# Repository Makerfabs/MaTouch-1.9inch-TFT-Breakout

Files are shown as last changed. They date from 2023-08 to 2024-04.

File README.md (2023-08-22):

MaTouch 1.9“ TFT Breakout

```c++
/*
Version:		V1.1
Author:		Charlin
Create Date:	2023/8/14
Note:

*/
```

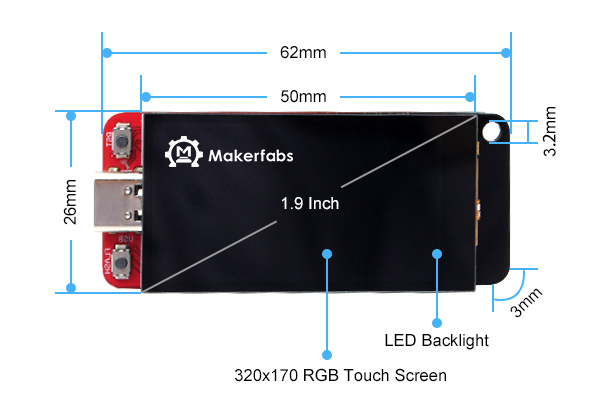
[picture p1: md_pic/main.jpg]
main


# Makerfabs

[Makerfabs home page](https://www.makerfabs.com/)

[Makerfabs Wiki](https://wiki.makerfabs.com/)

## Intruduce

Product Link:[MaTouch 1.9“ TFT Breakout](https://www.makerfabs.com/MaTouch-1.9-inch-TFT-Breakout.html)

Wiki Link : []()

Makerfabs MaTouch 1.9” has got lots of interests, but we got many feedback that there the ESP32S3 pins should be breakout, for users’ application, so we designed this new board.

Compares to the old version, there main updates are the GPIO all been breakout, users can prototype it more easily with a breadboard, or use it as a “controller” for other boards by inserting it to other boards.

## Features

Specs:
- Controller: ESP32-S3
- Wireless: WiFi& Bluetooth 5.0
- LCD: 1.9", 320x170 resolution, driver ST7789V2
- LCD interface: 8 bit 8080
- Touch Panel Driver: CST816D
- USB: USB Native, Type-C
- Power Supply: USB Type-C 5.0V(4.0V~5.25V); 3.7V Lipo battery
- Button: Flash button and reset button
- MicroSD: Yes
- Arduino support: Yes
- MicroPython support: Yes
- Operation temperature: -40℃ to +85℃

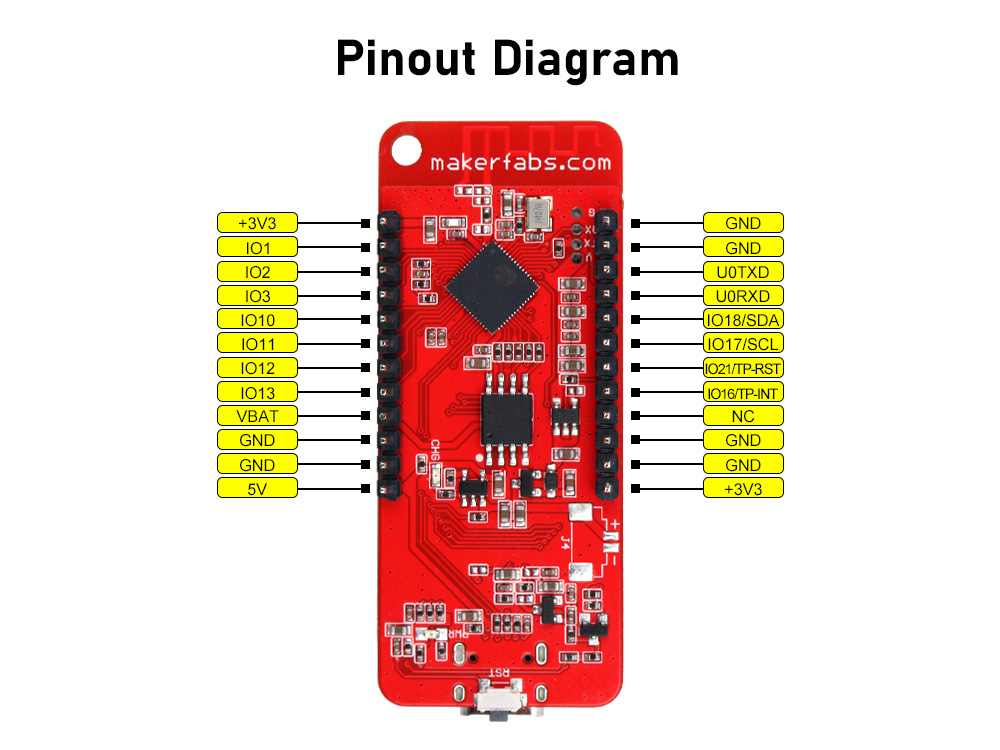
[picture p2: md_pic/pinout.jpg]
pinout


# Usage

## Libraries

Related library versions

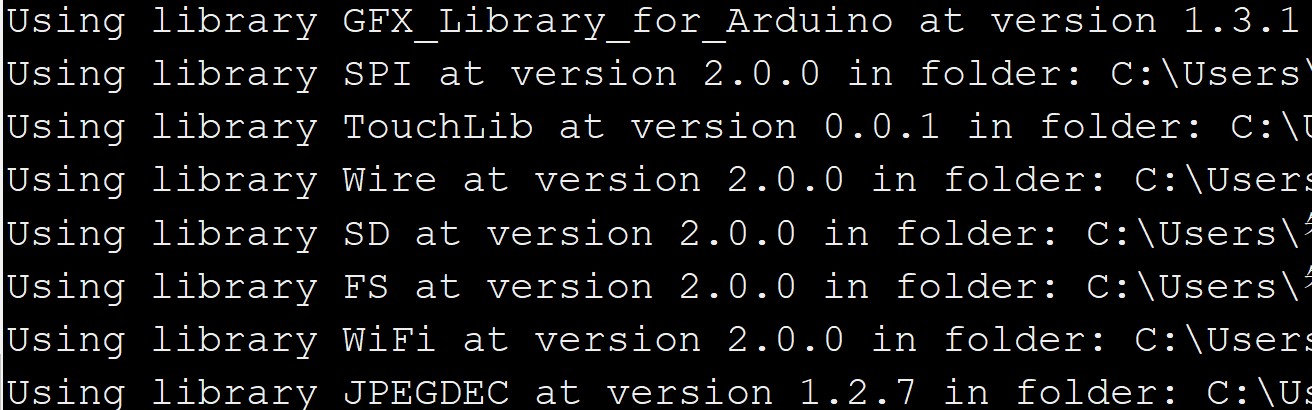
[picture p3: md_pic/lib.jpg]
library


- Use type-c use cable connect USB-TTL to PC.
- Select "ESP32-S3 DEV Module"
- Select PSRAM "OPI PSRAM"

"mf_Lvgl" library is modified from Lvgl library (version 8.3.2). 

Please unzip "lib/mf_Lvgl.zip"."TouchLib" and copy to arduino library directory.

## Example

### firmware

Factory test program

### squareline_demo

SquareLine demo, connected DHT11 sensor, button, LED.

[Youtube](https://www.youtube.com/watch?v=VayIuLey8po&t=3s)

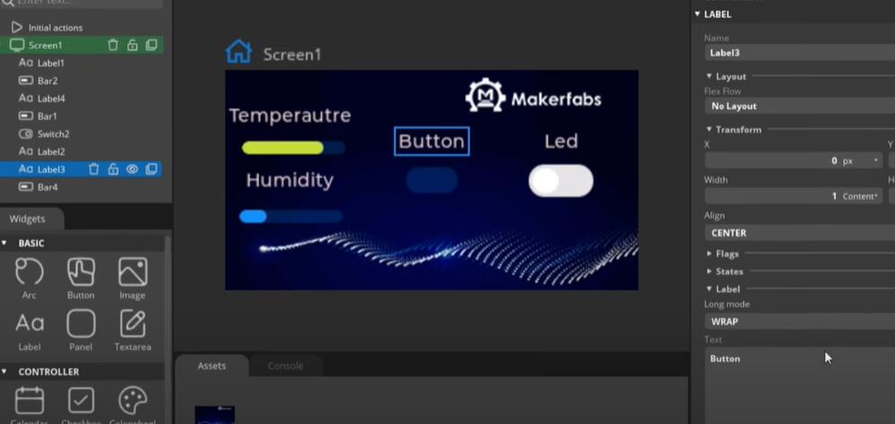
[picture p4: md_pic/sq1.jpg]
sq1


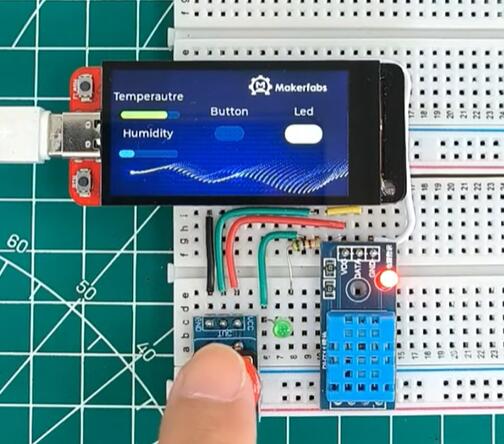
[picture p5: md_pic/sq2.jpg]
sq2


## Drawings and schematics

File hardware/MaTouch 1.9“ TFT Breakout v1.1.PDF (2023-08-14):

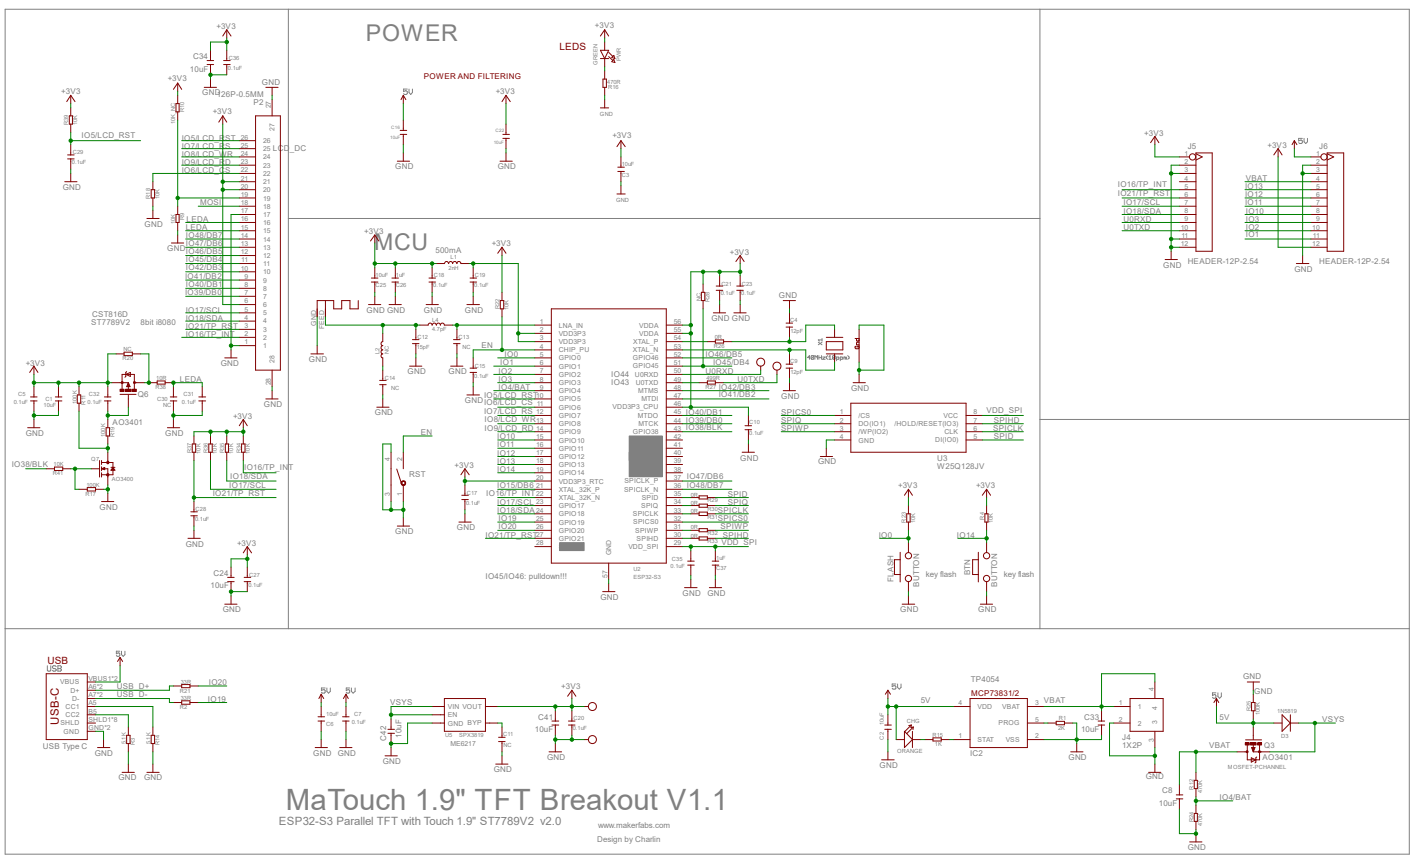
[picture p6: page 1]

+3V3 10K IO7/LCD_RS

IO8/LCD_WR

GND
RST MaTouch 1.9" TFT Breakout V1.1

ESP32-S3 Parallel TFT with Touch 1.9" ST7789V2 v2.0

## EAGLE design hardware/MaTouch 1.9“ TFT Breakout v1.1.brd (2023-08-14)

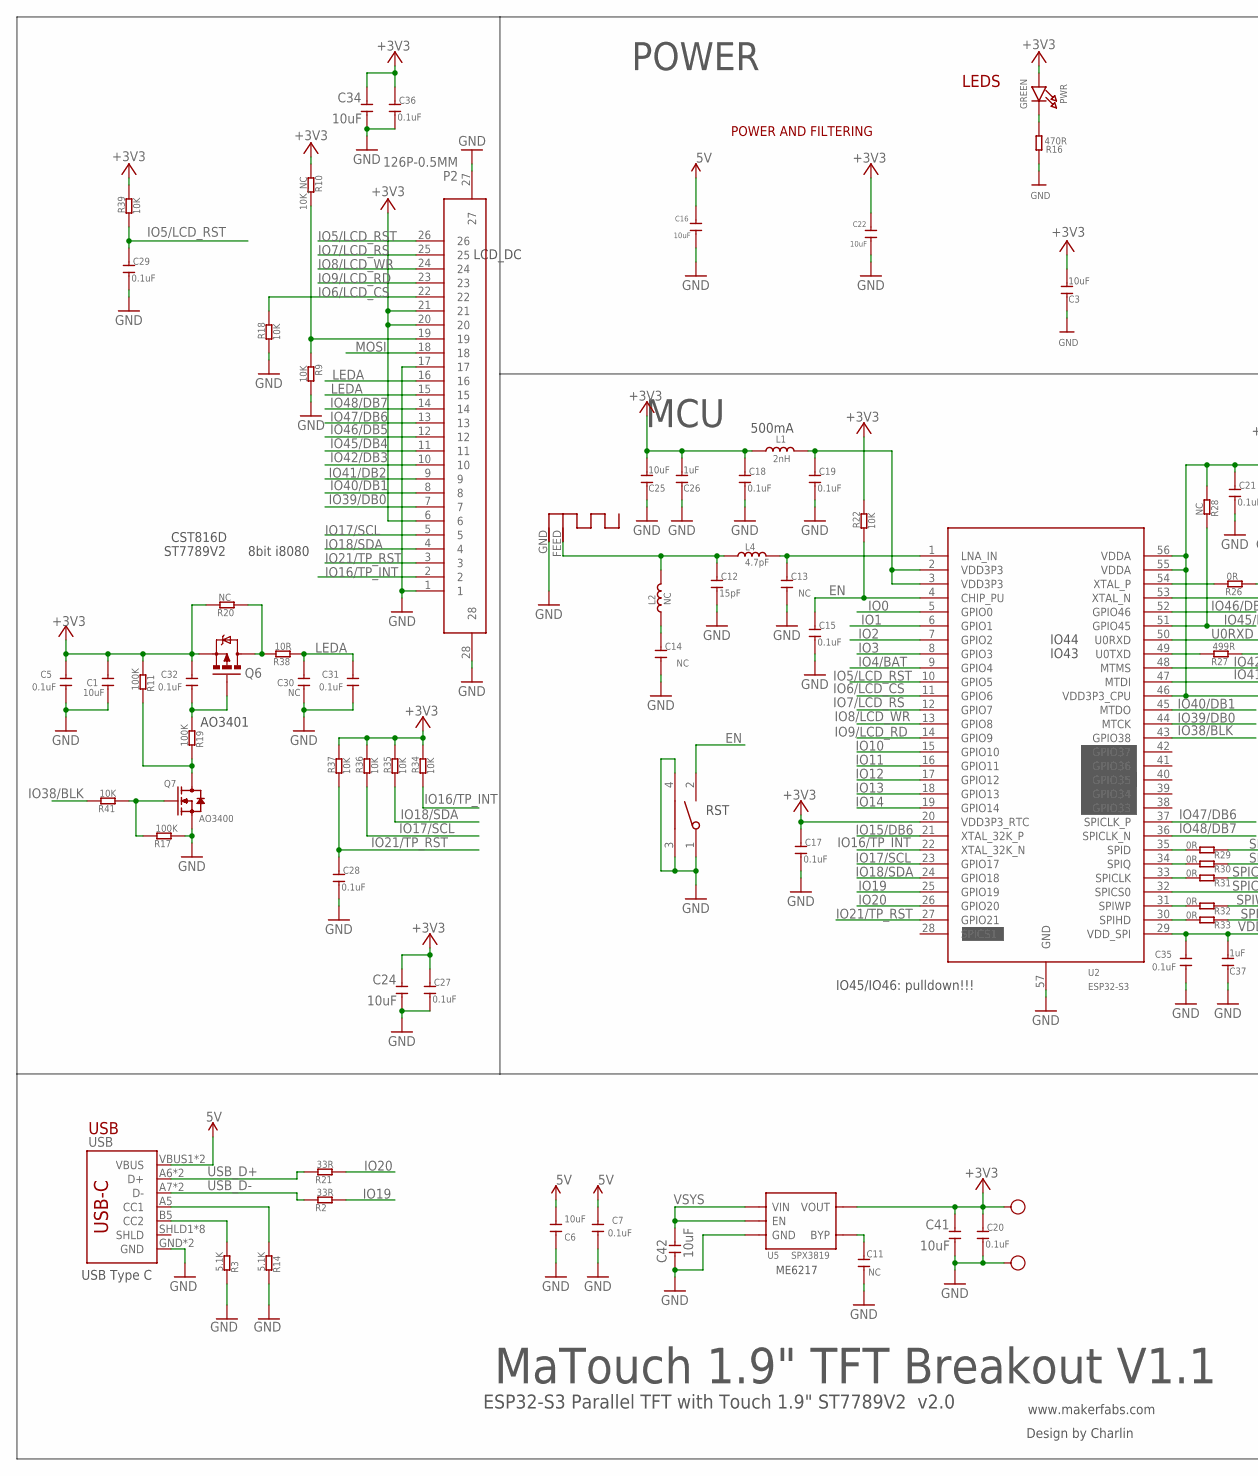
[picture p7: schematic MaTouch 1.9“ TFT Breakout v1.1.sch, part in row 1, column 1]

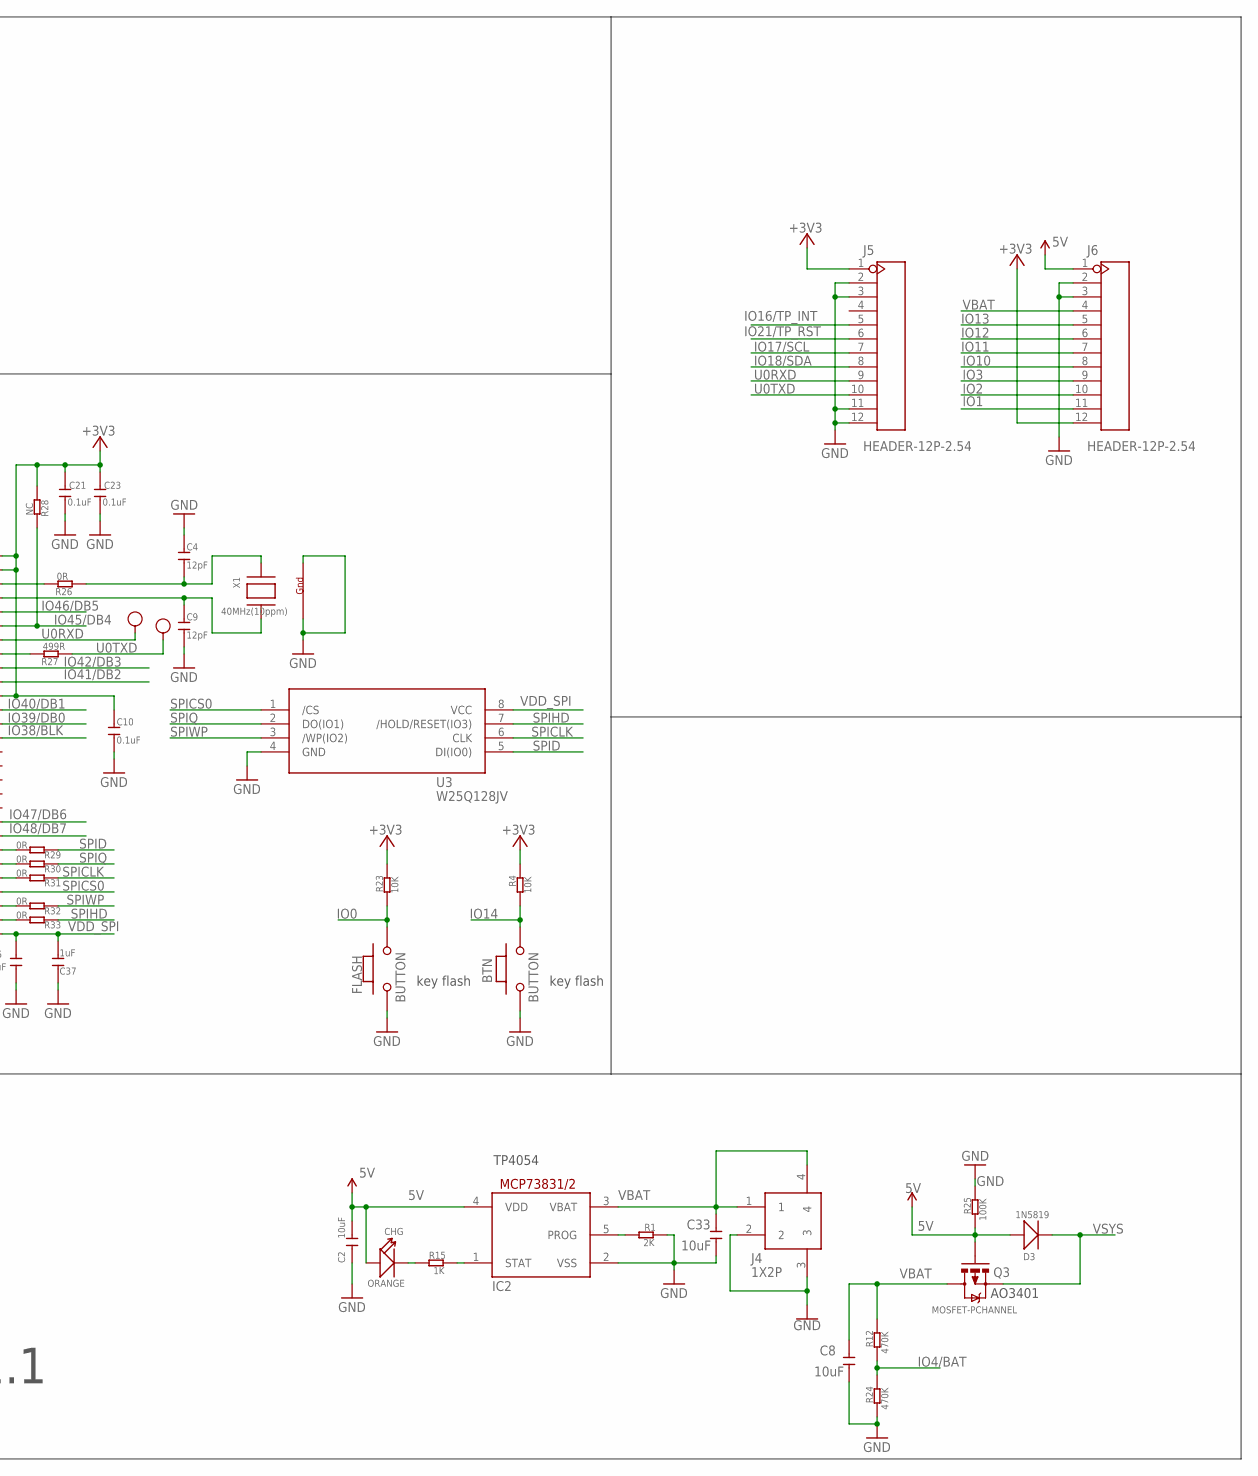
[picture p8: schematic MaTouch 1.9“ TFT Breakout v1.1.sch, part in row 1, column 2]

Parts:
ANT1: ANTENNA; RN-ANT
BTN: BUTTON; 157SW
C1, C2, C8, C16, C22, C24, C33, C34, C41, C42: 10uF; 0603
C3, C6, C25: 10uF; DISCRETE_C0603
C4, C9: 12pF; DISCRETE_C0402
C5, C7, C10, C15, C17, C18, C19, C20, C21, C23, C27, C28, C29, C31, C32, C35, C36: 0.1uF; DISCRETE_C0402
C11, C13, C14: NC; DISCRETE_C0402
C12: 15pF; DISCRETE_C0402
C26, C37: 1uF; DISCRETE_C0603
C30: NC; 0603
CHG: ORANGE; D0603
D3: 1N5819; SOD323
FLASH: BUTTON; 157SW
G: TEST-POINT'4545'; TP-D45MIL; PARTNO DNP
IC2: MCP73831/OT; SOT23-5L
J4: 1X2P; 1X2P-SMT1.25MM
J5, J6: HEADER-12P-2.54; 12P-2.54
L1: 2nH; DISCRETE_L0603
L2: NC; DISCRETE_L0402
L4: 4.7pF; DISCRETE_L0402
P2: 126P-0.5MM; 1*26P-SMT0.5MM
PWR: GREEN; CHIPLED_0805_NOOUTLINE
Q3, Q6: MOSFET-PCHANNEL; SOT23-3
Q7: AO3400; DISCRETE_SOT23
R1: 2K; DISCRETE_R0402
R2, R21: 33R; DISCRETE_R0402
R3, R14: 5.1K; DISCRETE_R0402
R4, R9, R18, R22, R23, R34, R35, R36, R37, R39, R41: 10K; DISCRETE_R0402
R10: 10K_NC; DISCRETE_R0402
R11, R17, R19, R25: 100K; DISCRETE_R0402
R12, R24: 470K; DISCRETE_R0402
R15: 1K; DISCRETE_R0402
R16: 470R; DISCRETE_R0402
R20, R28: NC; DISCRETE_R0402
R26, R29, R30, R31, R32, R33: 0R; DISCRETE_R0402
R27: 499R; DISCRETE_R0402
R38: 10R; DISCRETE_R0402
RST: TS24CA; 2*4*3.5MM
RX: TEST-POINT'4545'; TP-D45MIL; PARTNO DNP
TX: TEST-POINT'4545'; TP-D45MIL; PARTNO DNP
U2: ESP32-S3; QFN56-7*7MM
U3: W25Q128JV; SOIC-8-208MIL
U5: SPX3819; SOT23-5
USB: USB_C5; USB-C-16P-5
V: TEST-POINT'4545'; TP-D45MIL; PARTNO DNP
X1: 40MHz(10ppm); NX3225

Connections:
5V: C2.2, C6.2, C7.2, C16.1, CHG.+, D3.+, IC2.4 (VDD), J6.1, Q3.1 (G), R25.1, USB.VBUS1 (VBUS), USB.VBUS2 (VBUS)
+3V3: C1.2, C3.2, C5.2, C10.2, C17.2, C18.2, C20.2, C21.2, C22.1, C23.2, C24.2, C25.2, C26.2, C27.2, C32.2, C34.2, C36.2, C41.2, J5.1, J6.12, L1.1, P2.6, P2.20, P2.21, PWR.A, Q6.2 (S), R4.2, R10.2, R11.1, R20.2, R22.2, R23.2, R28.1, R34.2, R35.2, R36.2, R37.2, R39.2, U2.20 (VDD3P3_RTC), U2.46 (VDD3P3_CPU), U2.55 (VDDA), U2.56 (VDDA), U5.5 (VOUT), V.T
EN: C15.2, R22.1, RST.2, U2.4 (CHIP_PU)
GND: ANT1.GND, BTN.1, C1.1, C2.1, C3.1, C4.2, C5.1, C6.1, C7.1, C8.1, C9.1, C10.1, C11.1, C12.1, C13.1, C14.1, C15.1, C16.2, C17.1, C18.1, C19.1, C20.1, C21.1, C22.2, C23.1, C24.1, C25.1, C26.1, C27.1, C28.1, C29.1, C30.1, C31.1, C33.1, C34.1, C35.1, C36.1, C37.1, C41.1, C42.1, FLASH.1, G.T, IC2.2 (VSS), J4.2, J4.3, J5.2, J5.3, J5.11, J5.12, J6.2, J6.3, P2.1, P2.17, P2.27, P2.28, Q7.2 (S), R1.2, R3.2, R9.1, R14.2, R16.1, R17.1, R18.1, R24.1, R25.2, RST.1, RST.3, RST.4, U2.57 (GND), U3.4 (GND), U5.2 (GND), USB.GND, USB.GND2 (GND), X1.2 (G2), X1.4 (G1)
IO0: FLASH.2, R23.1, U2.5 (GPIO0)
IO1: J6.11, U2.6 (GPIO1)
IO2: J6.10, U2.7 (GPIO2)
IO3: J6.9, U2.8 (GPIO3)
IO4/BAT: R12.1, R24.2, U2.9 (GPIO4)
IO5/LCD_RST: C29.2, P2.26, R39.1, U2.10 (GPIO5)
IO6/LCD_CS: P2.22, R18.2, U2.11 (GPIO6)
IO7/LCD_RS: P2.25, U2.12 (GPIO7)
IO8/LCD_WR: P2.24, U2.13 (GPIO8)
IO9/LCD_RD: P2.23, U2.14 (GPIO9)
IO10: J6.8, U2.15 (GPIO10)
IO11: J6.7, U2.16 (GPIO11)
IO12: J6.6, U2.17 (GPIO12)
IO13: J6.5, U2.18 (GPIO13)
IO14: BTN.2, R4.1, U2.19 (GPIO14)
IO15/DB6: U2.21 (XTAL_32K_P)
IO16/TP_INT: J5.5, P2.2, R34.1, U2.22 (XTAL_32K_N)
IO17/SCL: J5.7, P2.5, R36.1, U2.23 (GPIO17)
IO18/SDA: J5.8, P2.4, R35.1, U2.24 (GPIO18)
IO19: R2.1, U2.25 (GPIO19)
IO20: R21.1, U2.26 (GPIO20)
IO21/TP_RST: C28.2, J5.6, P2.3, R37.1, U2.27 (GPIO21)
IO38/BLK: R41.2, U2.43 (GPIO38)
IO39/DB0: P2.7, U2.44 (MTCK)
IO40/DB1: P2.8, U2.45 (MTDO)
IO41/DB2: P2.9, U2.47 (MTDI)
IO42/DB3: P2.10, U2.48 (MTMS)
IO45/DB4: P2.11, R28.2, U2.51 (GPIO45)
IO46/DB5: P2.12, U2.52 (GPIO46)
IO47/DB6: P2.13, U2.37 (SPICLK_P)
IO48/DB7: P2.14, U2.36 (SPICLK_N)
LEDA: C30.2, C31.2, P2.15, P2.16, R38.1
MOSI: P2.18
unnamed: IC2.5 (PROG), R1.1
unnamed: C32.1, Q6.1 (G), R19.1
unnamed: R14.1, USB.A5 (CC1)
unnamed: PWR.C, R16.2
unnamed: P2.19, R9.2, R10.1
unnamed: Q6.3 (D), R20.1, R38.2
unnamed: R3.1, USB.B5 (CC2)
unnamed: Q7.3 (D), R11.2, R19.2
unnamed: Q7.1 (G), R17.2, R41.1
unnamed: CHG.-, R15.1
unnamed: IC2.1 (STAT), R15.2
unnamed: ANT1.FEED, C12.2, L2.2, L4.1
unnamed: C13.2, L4.2, U2.1 (LNA_IN)
unnamed: R29.2, U2.35 (SPID)
unnamed: C19.2, L1.2, U2.2 (VDD3P3), U2.3 (VDD3P3)
unnamed: C14.2, L2.1
unnamed: R30.2, U2.34 (SPIQ)
unnamed: R26.2, U2.54 (XTAL_P)
unnamed: R31.2, U2.33 (SPICLK)
unnamed: R32.2, U2.31 (SPIWP)
unnamed: R33.2, U2.30 (SPIHD)
unnamed: R27.2, U2.49 (U0TXD)
unnamed: C9.2, U2.53 (XTAL_N), X1.3 (X2)
unnamed: C4.1, R26.1, X1.1 (X1)
unnamed: C11.2, U5.4 (BYP)
SPICLK: R31.1, U3.6 (CLK)
SPICS0: U2.32 (SPICS0), U3.1 (/CS)
SPID: R29.1, U3.5 (DI(IO0))
SPIHD: R33.1, U3.7 (/HOLD/RESET(IO3))
SPIQ: R30.1, U3.2 (DO(IO1))
SPIWP: R32.1, U3.3 (/WP(IO2))
U0RXD: J5.9, RX.T, U2.50 (U0RXD)
U0TXD: J5.10, R27.1, TX.T
USB_D+: R21.2, USB.A6 (D+), USB.B6 (D+)
USB_D-: R2.2, USB.A7 (D-), USB.B7 (D-)
VBAT: C8.2, C33.2, IC2.3 (VBAT), J4.1, J4.4, J6.4, Q3.3 (D), R12.2
VDD_SPI: C35.2, C37.2, U2.29 (VDD_SPI), U3.8 (VCC)
VSYS: C42.2, D3.-, Q3.2 (S), U5.1 (VIN), U5.3 (EN)

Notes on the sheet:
www.makerfabs.com
Design by Charlin
LEDS
POWER AND FILTERING
key flash
ESP32-S3 Parallel TFT with Touch 1.9" ST7789V2 v2.0
POWER
USB
USB Type C
MCU
500mA
ME6217
TP4054
AO3401
8bit i8080
IO45/IO46: pulldown!!!
IO43
IO44
CST816D
ST7789V2
LCD_DC
RST
MaTouch 1.9" TFT Breakout V1.1

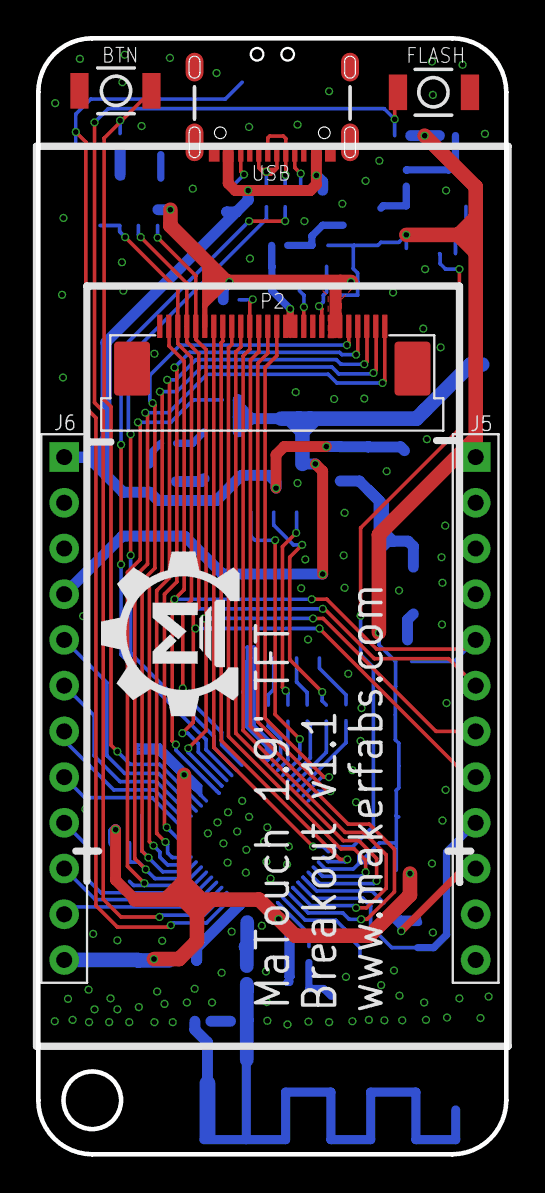
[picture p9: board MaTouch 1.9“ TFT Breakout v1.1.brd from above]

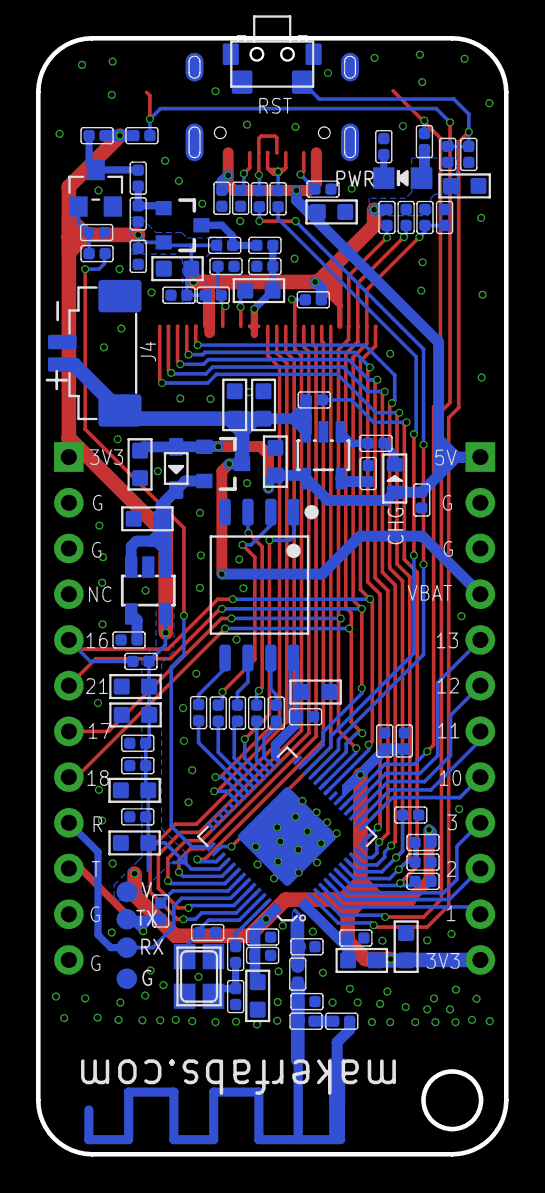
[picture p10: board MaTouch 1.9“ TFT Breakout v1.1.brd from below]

Board: 2 copper layers, 26.0 x 62.0 mm, 102 parts (95 on the bottom side), 73 nets.

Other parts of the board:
U$1: MAKERFABS_0.3

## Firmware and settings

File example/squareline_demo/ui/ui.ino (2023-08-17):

#include <lvgl.h>
#include <Arduino_GFX_Library.h>
#include "ui.h"
#include "DHT.h"
#include "pin_config.h"

#define TOUCH_MODULES_CST_SELF
#include <TouchLib.h>

#define DHTPIN 1      // Digital pin connected to the DHT sensor
#define DHTTYPE DHT11 // DHT 11

#define BUTTON_PIN 2
#define LED_PIN 3

static const uint16_t screenWidth = 320;
static const uint16_t screenHeight = 170;

static lv_disp_draw_buf_t draw_buf;
static lv_color_t buf[screenWidth * screenHeight / 10];

Arduino_DataBus *bus = new Arduino_ESP32LCD8(7 /* DC */, 6 /* CS */, 8 /* WR */, 9 /* RD */, 39 /* D0 */, 40 /* D1 */, 41 /* D2 */, 42 /* D3 */,
                                             45 /* D4 */, 46 /* D5 */, 47 /* D6 */, 48 /* D7 */);

Arduino_GFX *gfx = new Arduino_ST7789(bus, 5 /* RST */, 0 /* rotation */, true /* IPS */, 170 /* width */, 320 /* height */, 35 /* col offset 1 */,
                                      0 /* row offset 1 */, 35 /* col offset 2 */, 0 /* row offset 2 */);

TouchLib touch(Wire, PIN_IIC_SDA, PIN_IIC_SCL, CTS820_SLAVE_ADDRESS, PIN_TOUCH_RES);

DHT dht(DHTPIN, DHTTYPE);

float temperature = 0.0;
float humidity = 0.0;
int led_flag = 0;
int led_status = 1;

void setup()
{
    USBSerial.begin(115200); /* prepare for possible serial debug */

    pinMode(BUTTON_PIN, INPUT_PULLUP);
    pinMode(LED_PIN, OUTPUT);
    digitalWrite(LED_PIN, led_status);

    pinMode(PIN_LCD_BL, OUTPUT);
    digitalWrite(PIN_LCD_BL, HIGH);

    pinMode(PIN_LCD_RST, OUTPUT);
    digitalWrite(PIN_LCD_RST, HIGH);

    pinMode(PIN_TOUCH_RES, OUTPUT);
    digitalWrite(PIN_TOUCH_RES, LOW);
    delay(500);
    digitalWrite(PIN_TOUCH_RES, HIGH);

    ledcSetup(0, 2000, 8);
    ledcAttachPin(PIN_LCD_BL, 0);
    ledcWrite(0, 255);

    Wire.begin(PIN_IIC_SDA, PIN_IIC_SCL);
    if (!touch.init())
    {
        USBSerial.println("Touch IC not found");
        Serial.println("Touch IC not found");
    }

    dht.begin();

    gfx->begin();
    gfx->setRotation(1);

    String LVGL_Arduino = "Hello Arduino! ";
    LVGL_Arduino += String('V') + lv_version_major() + "." + lv_version_minor() + "." + lv_version_patch();

    USBSerial.println(LVGL_Arduino);
    USBSerial.println("I am LVGL_Arduino");

    lv_init();
    lv_disp_draw_buf_init(&draw_buf, buf, NULL, screenWidth * screenHeight / 10);

    /*Initialize the display*/
    static lv_disp_drv_t disp_drv;
    lv_disp_drv_init(&disp_drv);
    /*Change the following line to your display resolution*/
    disp_drv.hor_res = screenWidth;
    disp_drv.ver_res = screenHeight;
    disp_drv.flush_cb = my_disp_flush;
    disp_drv.draw_buf = &draw_buf;
    lv_disp_drv_register(&disp_drv);

    /*Initialize the (dummy) input device driver*/
    static lv_indev_drv_t indev_drv;
    lv_indev_drv_init(&indev_drv);
    indev_drv.type = LV_INDEV_TYPE_POINTER;
    indev_drv.read_cb = my_touchpad_read;
    lv_indev_drv_register(&indev_drv);

    ui_init();

    USBSerial.println("Setup done");

    xTaskCreatePinnedToCore(Task_TFT, "Task_TFT", 20480, NULL, 3, NULL, 0);
    xTaskCreatePinnedToCore(Task_my, "Task_my", 40960, NULL, 3, NULL, 1);
}

void loop()
{
}

// -------------------------------------------------------------------------------------

void Task_TFT(void *pvParameters)
{
    while (1)
    {
        lv_timer_handler();
        vTaskDelay(10);
    }
}

void Task_my(void *pvParameters)
{
    long task_runtime_1 = 0;
    long task_runtime_2 = 0;
    long task_runtime_3 = 0;
    while (1)
    {
        if ((millis() - task_runtime_1) > 5000)
        {
            my_func_1();
            task_runtime_1 = millis();
        }
        if ((millis() - task_runtime_2) > 100)
        {
            my_func_2();
            task_runtime_2 = millis();
        }
        if ((millis() - task_runtime_3) > 200)
        {
            my_func_3();
            task_runtime_3 = millis();
        }
        vTaskDelay(100);
    }
}

void my_func_1()
{
    sensor_read();

    lv_bar_set_value(ui_Bar1, (int)temperature, LV_ANIM_OFF);
    lv_bar_set_value(ui_Bar2, (int)humidity, LV_ANIM_OFF);

    char temp[20];
    sprintf(temp, "Temp:\t%.1f C", temperature);
    lv_label_set_text(ui_Label1, temp);
    sprintf(temp, "Humi:\t%.1f %%", humidity);
    lv_label_set_text(ui_Label4, temp);
}

void my_func_2()
{
    if (digitalRead(BUTTON_PIN) == 1)
    {
        USBSerial.println("Button Presh");
        lv_bar_set_value(ui_Bar4, 1, LV_ANIM_OFF);
        // lv_obj_add_state(ui_Switch1, LV_STATE_CHECKED);
        // lv_switch_on(ui_Switch1, LV_ANIM_ON)
    }
    else
    {
        lv_bar_set_value(ui_Bar4, 0, LV_ANIM_OFF);
        // lv_obj_clear_state(ui_Switch1, LV_STATE_CHECKED);
        // lv_switch_off(ui_Switch1, LV_ANIM_ON)
        // USBSerial.println("Button Release");
    }
}

void my_func_3()
{
    if (led_flag == 1)
    {
        USBSerial.println("Led Toggle");
        // USBSerial.println(lv_obj_get_state());
        led_status = (led_status + 1) % 2;
        digitalWrite(LED_PIN, led_status);
        led_flag = 0;
    }
}

void sensor_read()
{
    humidity = dht.readHumidity();
    temperature = dht.readTemperature();

    USBSerial.print(F("Humidity: "));
    USBSerial.print(humidity);
    USBSerial.print(F("%  Temperature: "));
    USBSerial.print(temperature);
    USBSerial.println(F("°C "));
}

//------------------------------------------------------------------------

/* Display flushing */
void my_disp_flush(lv_disp_drv_t *disp, const lv_area_t *area, lv_color_t *color_p)
{
    uint32_t w = (area->x2 - area->x1 + 1);
    uint32_t h = (area->y2 - area->y1 + 1);

#if (LV_COLOR_16_SWAP != 0)
    gfx->draw16bitBeRGBBitmap(area->x1, area->y1, (uint16_t *)&color_p->full, w, h);
#else
    gfx->draw16bitRGBBitmap(area->x1, area->y1, (uint16_t *)&color_p->full, w, h);
#endif

    lv_disp_flush_ready(disp);
}

/*Read the touchpad*/
void my_touchpad_read(lv_indev_drv_t *indev_driver, lv_indev_data_t *data)
{
    uint16_t touchX = 0, touchY = 0;

    if (touch.read())
    {
        data->state = LV_INDEV_STATE_PR;

        uint8_t n = touch.getPointNum();
        for (uint8_t i = 0; i < n; i++)
        {
            TP_Point t = touch.getPoint(i);
            int temp_x = t.y;
            int temp_y = map(t.x, 0, 150, 170, 0);

            // USBSerial.println(temp_x);
            // USBSerial.println(temp_y);

            data->point.x = temp_x;
            data->point.y = temp_y;
            break;
        }
    }
    else
    {
        data->state = LV_INDEV_STATE_REL;
    }
}

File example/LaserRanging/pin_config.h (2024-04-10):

#define PIN_LCD_BL 38

#define PIN_LCD_D0 39
#define PIN_LCD_D1 40
#define PIN_LCD_D2 41
#define PIN_LCD_D3 42
#define PIN_LCD_D4 45
#define PIN_LCD_D5 46
#define PIN_LCD_D6 47
#define PIN_LCD_D7 48

#define PIN_LCD_RST 1
#define PIN_LCD_CS 6
#define PIN_LCD_DC 7 // RS
#define PIN_LCD_WR 8
#define PIN_LCD_RD 9

#define PIN_BUTTON_1 0
#define PIN_BUTTON_2 14
#define PIN_BAT_VOLT 4

#define PIN_IIC_SCL 17
#define PIN_IIC_SDA 18

#define PIN_TOUCH_INT 16
#define PIN_TOUCH_RES 21

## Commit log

2023-08-14 The hardware and default code
    [MaTouch 1.9“ TFT Breakout v1.1.brd, MaTouch 1.9“ TFT Breakout v1.1.sch]
2024-04-10 Add laser ranging demo

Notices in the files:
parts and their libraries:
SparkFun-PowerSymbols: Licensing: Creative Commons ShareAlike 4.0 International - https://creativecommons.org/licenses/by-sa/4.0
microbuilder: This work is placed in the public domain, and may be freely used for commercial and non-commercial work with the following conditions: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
